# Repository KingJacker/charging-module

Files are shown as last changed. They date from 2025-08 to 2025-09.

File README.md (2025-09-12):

# charging-module

## Requirements

- Reverse Polarity Protection
- Overvoltage Protection
- Undervoltage Protection
- PowerPath Passthorugh (Allow Load while charging)
- Overtemperature Protection
- Big Package (easy to solder)
- LED Charge indicators
- Adjustable Charge Current up to 1A

- (Regulated output?)

## Selected IC

### MCP73871

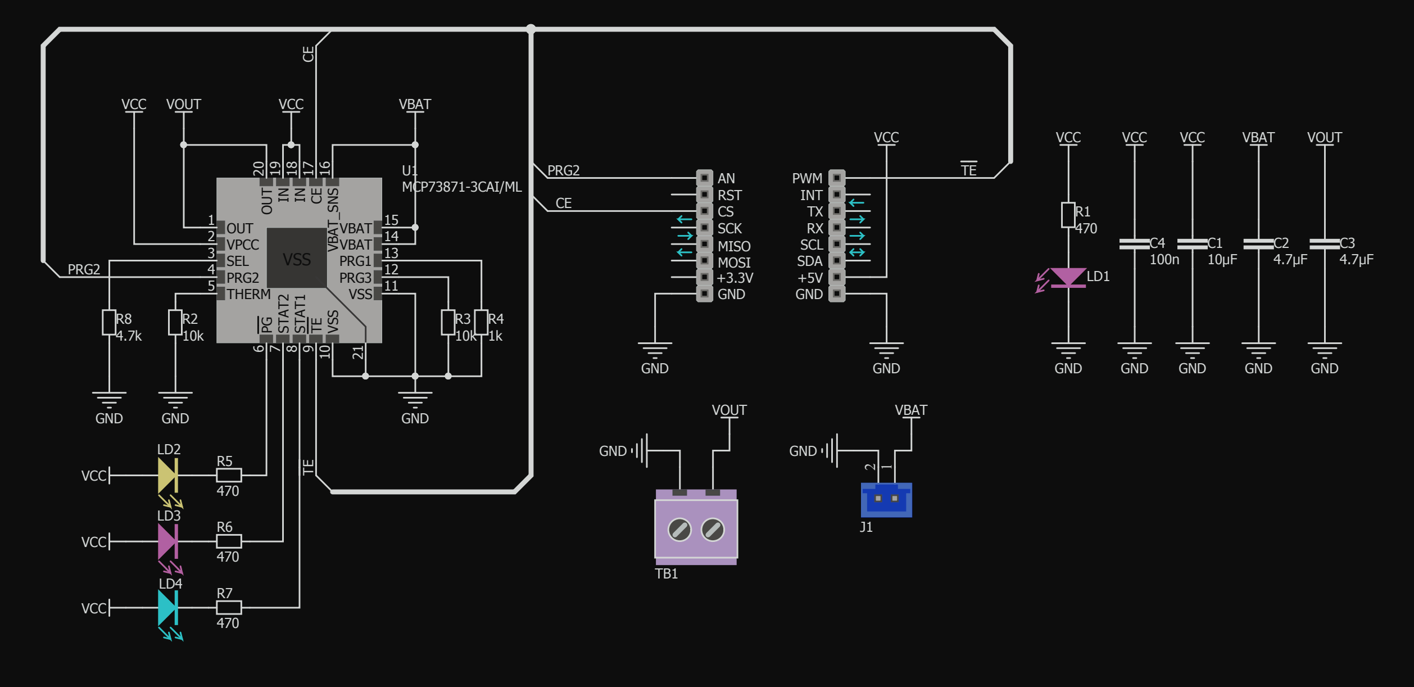
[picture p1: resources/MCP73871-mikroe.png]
Example Schematic (Mikroe)


**Requires choosing an input source:**

- USB: draws 100mAh to 500mAh (configurable)
- AC/DC Adapter: draw up to 1.8A

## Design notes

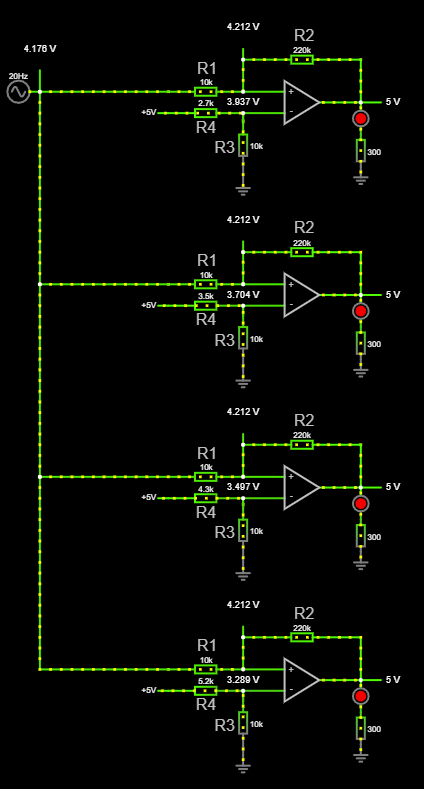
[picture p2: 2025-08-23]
resources/Voltage-Indicator.PNG

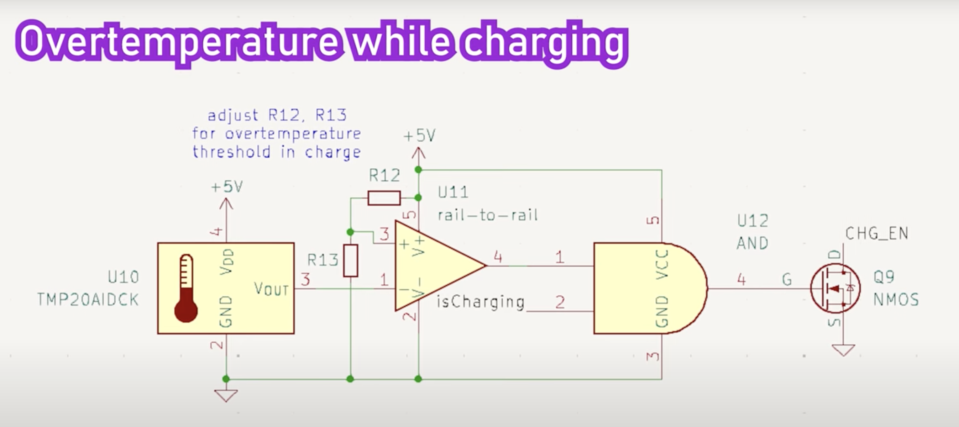
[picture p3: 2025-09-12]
resources/Overtemp.png

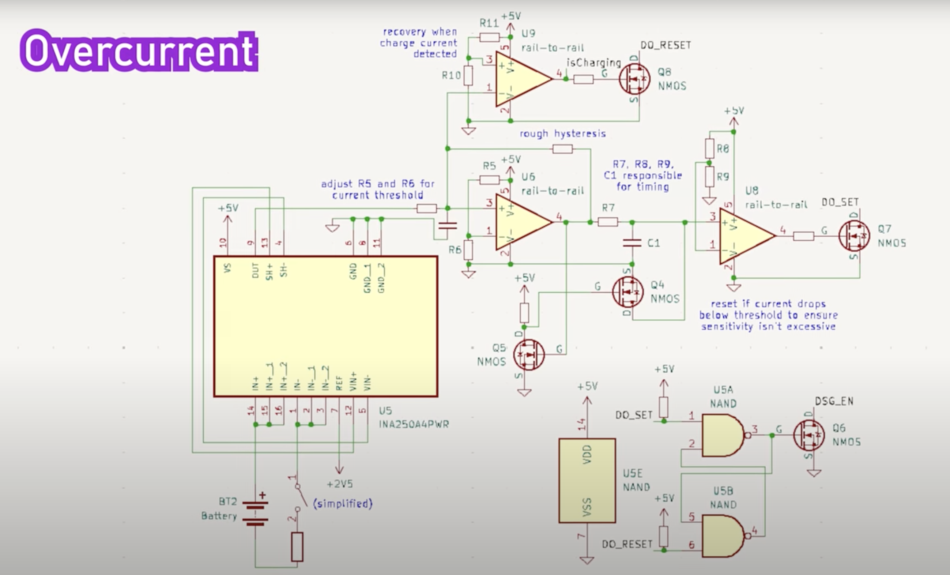
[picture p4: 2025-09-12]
resources/Overcurrent.png

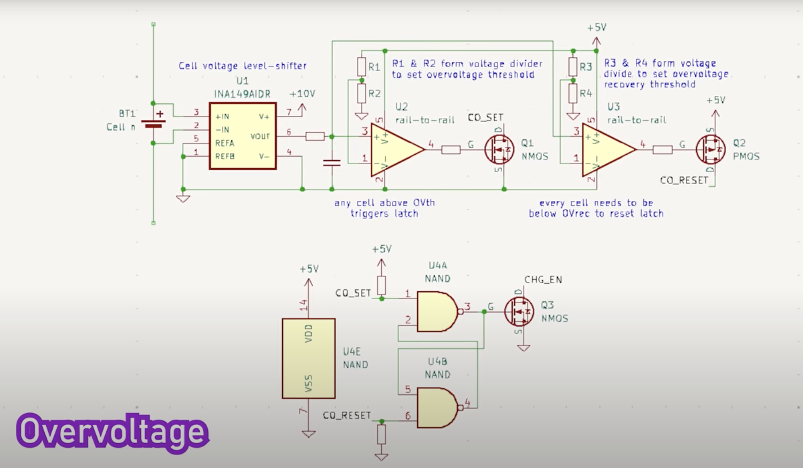
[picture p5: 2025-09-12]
resources/Overvoltage.png

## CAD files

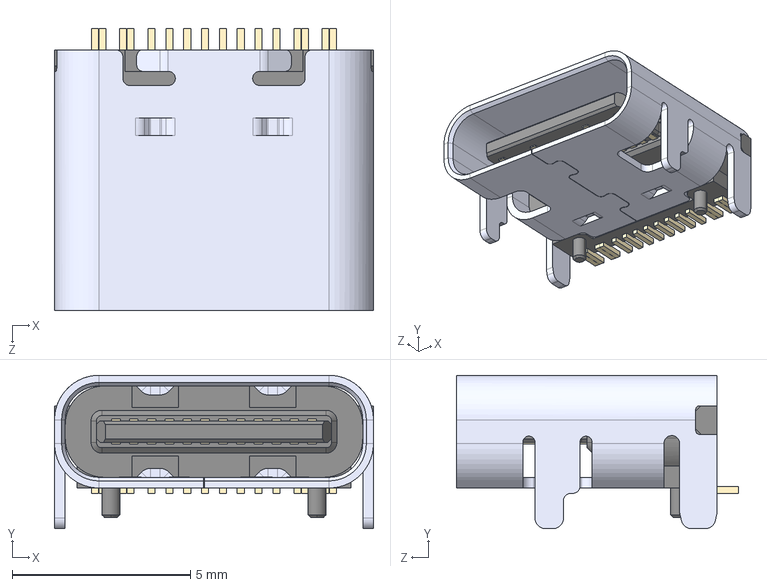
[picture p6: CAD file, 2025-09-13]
3d_models/TYPE-C-31-M-12--3DModel-STEP-56544.STEP
8.94 x 4.30 x 7.90 mm

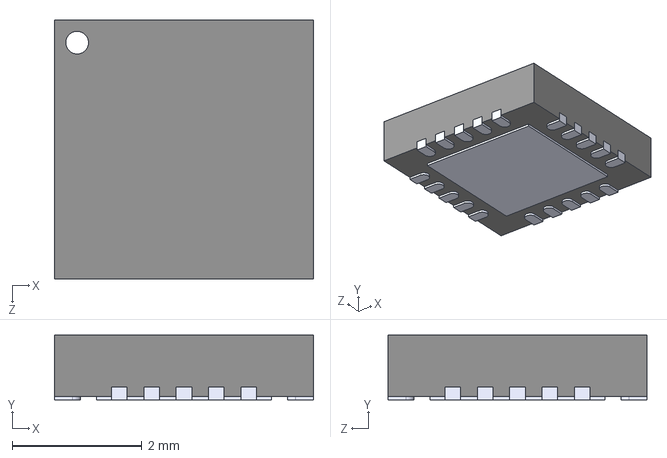
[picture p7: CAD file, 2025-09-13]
3d_models/MCP73871-2CAI_ML.STEP
4.00 x 1.00 x 4.00 mm

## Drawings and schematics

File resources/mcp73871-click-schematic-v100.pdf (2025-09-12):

# MCP73871 click schematic

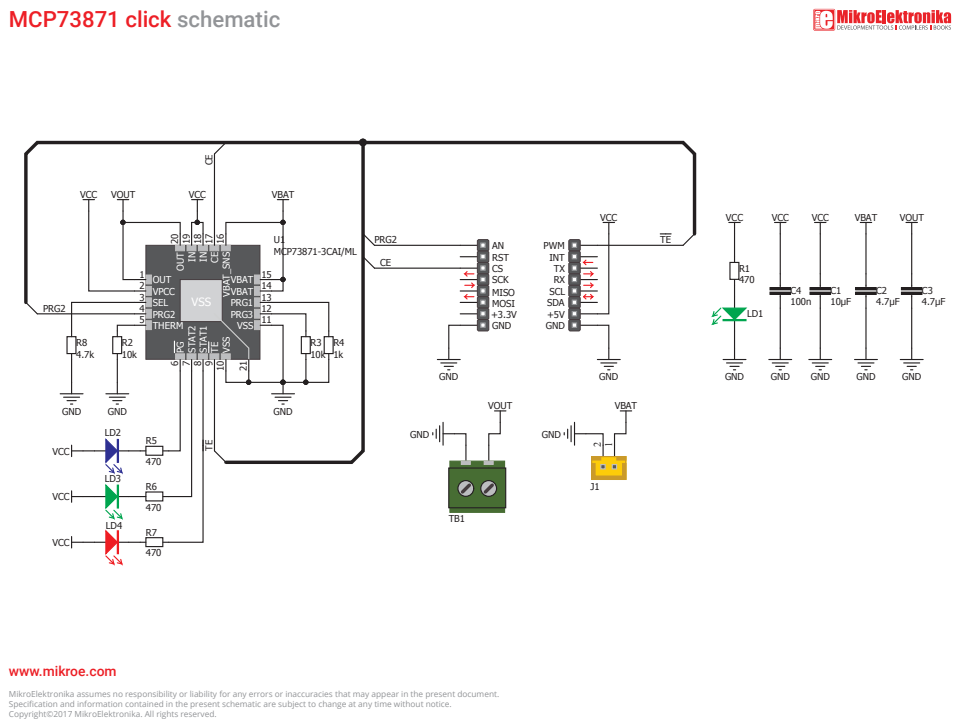
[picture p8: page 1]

MikroElektronika assumes no responsibility or liability for any errors or inaccuracies that may appear in the present document.
Specification and information contained in the present schematic are subject to change at any time without notice.
Copyright©2017 MikroElektronika. All rights reserved.

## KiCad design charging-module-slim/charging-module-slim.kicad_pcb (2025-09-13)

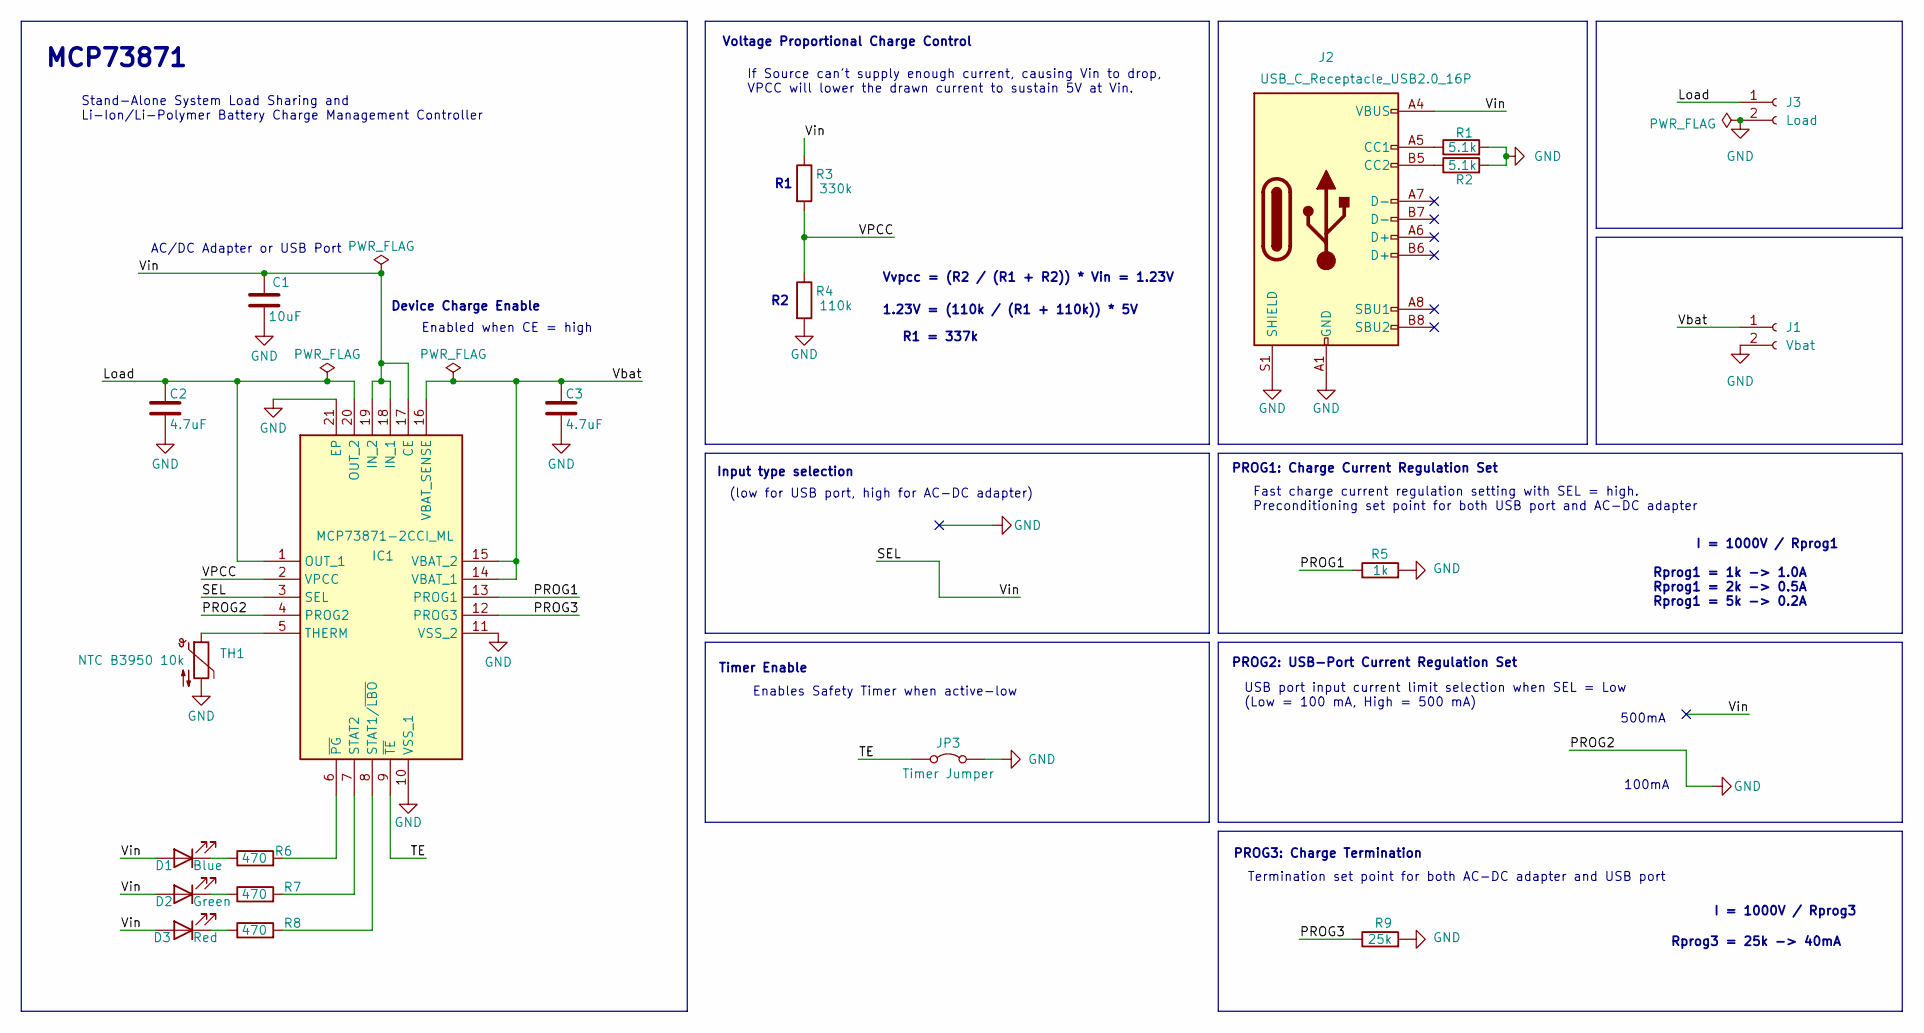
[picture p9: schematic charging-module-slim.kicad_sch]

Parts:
C1: 10uF; C_0805_2012Metric_Pad1.18x1.45mm_HandSolder
C2, C3: 4.7uF; C_0805_2012Metric_Pad1.18x1.45mm_HandSolder
D1: Blue; LED_0805_2012Metric_Pad1.15x1.40mm_HandSolder
D2: Green; LED_0805_2012Metric_Pad1.15x1.40mm_HandSolder
D3: Red; LED_0805_2012Metric_Pad1.15x1.40mm_HandSolder
IC1: MCP73871-2CCI_ML; QFN50P400X400X100-21N-D; Mouser Part Number 579-MCP73871-2CCI/ML
J1: Vbat; PinSocket_1x02_P2.00mm_Vertical
J2: USB_C_Receptacle_USB2.0_16P; USB_C_Receptacle_HRO_TYPE-C-31-M-12
J3: Load; PinSocket_1x02_P2.00mm_Vertical
JP3: Timer Jumper; SolderJumper-2_P1.3mm_Bridged_RoundedPad1.0x1.5mm
R1, R2: 5.1k; R_0805_2012Metric_Pad1.20x1.40mm_HandSolder
R3: 330k; R_0805_2012Metric_Pad1.20x1.40mm_HandSolder
R4: 110k; R_0805_2012Metric_Pad1.20x1.40mm_HandSolder
R5: 1k; R_0805_2012Metric_Pad1.20x1.40mm_HandSolder
R6, R7, R8: 470; R_0805_2012Metric_Pad1.20x1.40mm_HandSolder
R9: 25k; R_0805_2012Metric_Pad1.20x1.40mm_HandSolder
TH1: NTC B3950 10k; PinSocket_1x02_P2.00mm_Vertical

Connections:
/Load: C2.1, IC1.1 (OUT_1), IC1.20 (OUT_2), J3.1
/PROG1: IC1.13 (PROG1), R5.1
/PROG3: IC1.12 (PROG3), R9.1
/SEL: C1.1, D1.2 (A), D2.2 (A), D3.2 (A), IC1.3 (SEL), IC1.17 (CE), IC1.18 (IN_1), IC1.19 (IN_2), J2.A4 (VBUS), J2.A9 (VBUS), J2.B4 (VBUS), J2.B9 (VBUS), R3.1
/TE: IC1.9 (~TE), JP3.1 (A)
/VPCC: IC1.2 (VPCC), R3.2, R4.1
/Vbat: C3.1, IC1.14 (VBAT_1), IC1.15 (VBAT_2), IC1.16 (VBAT_SENSE), J1.1
GND: C1.2, C2.2, C3.2, IC1.4 (PROG2), IC1.10 (VSS_1), IC1.11 (VSS_2), IC1.21 (EP), J1.2, J2.A1 (GND), J2.A12 (GND), J2.B1 (GND), J2.B12 (GND), J2.S1 (SHIELD), J3.2, JP3.2 (B), R1.2, R2.2, R4.2, R5.2, R9.2, TH1.2
unnamed: D1.1 (K), R6.1
unnamed: D2.1 (K), R7.1
unnamed: D3.1 (K), R8.1
unnamed: IC1.8 (STAT1/~LBO), R8.2
unnamed: IC1.7 (STAT2), R7.2
unnamed: IC1.5 (THERM), TH1.1
unnamed: IC1.6 (~PG), R6.2
unnamed: J2.A5 (CC1), R1.1
unnamed: J2.B5 (CC2), R2.1

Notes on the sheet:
Vvpcc = (R2 / (R1 + R2)) * Vin = 1.23V
Stand-Alone System Load Sharing and Li-Ion/Li-Polymer Battery Charge Management Controller
Device Charge Enable
USB port input current limit selection when SEL = Low (Low = 100 mA, High = 500 mA)
AC/DC Adapter or USB Port
I = 1000V / Rprog1
PROG2: USB-Port Current Regulation Set
Enables Safety Timer when active-low
Fast charge current regulation setting with SEL = high. Preconditioning set point for both USB port and AC-DC adapter
MCP73871
Voltage Proportional Charge Control
Rprog1 = 1k -> 1.0A
500mA
If Source can't supply enough current, causing Vin to drop, VPCC will lower the drawn current to sustain 5V at Vin.
Rprog1 = 2k -> 0.5A
Enabled when CE = high
100mA
Termination set point for both AC-DC adapter and USB port
I = 1000V / Rprog3
Rprog1 = 5k -> 0.2A
PROG3: Charge Termination
1.23V = (110k / (R1 + 110k)) * 5V
Timer Enable
PROG1: Charge Current Regulation Set
(low for USB port, high for AC-DC adapter)
Input type selection
R1 = 337k
Rprog3 = 25k -> 40mA

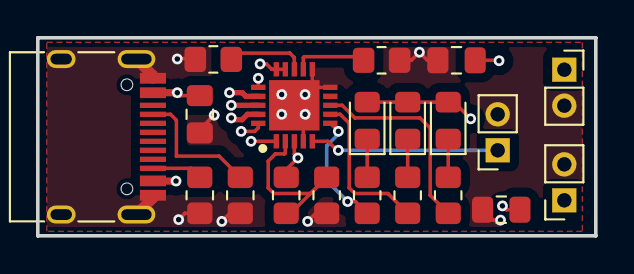
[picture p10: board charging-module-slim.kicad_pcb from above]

Board: 4 copper layers, 31.0 x 11.0 mm, 20 parts (0 on the bottom side), 16 nets.

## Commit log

2025-09-12 MCP73871 schematic
    [charging-module.kicad_sch]
2025-09-12 removed overvoltage diode
    [charging-module.kicad_sch]
2025-09-12 assigned footprints
    [charging-module.kicad_sch]
2025-09-12 started on layout
    [charging-module.kicad_pcb, charging-module.kicad_sch]
2025-09-13 layout done
    [MCP73871-2CAI_ML.STEP, TYPE-C-31-M-12--3DModel-STEP-56544.STEP, charging-module.kicad_pcb]
2025-09-13 layout slim
    [charging-module-slim-B_Cu.gbr, charging-module-slim-B_Mask.gbr, charging-module-slim-B_Paste.gbr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]
